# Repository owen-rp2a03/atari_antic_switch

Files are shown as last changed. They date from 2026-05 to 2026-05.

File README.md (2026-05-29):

# Atari NTSC/PAL Antic switch board

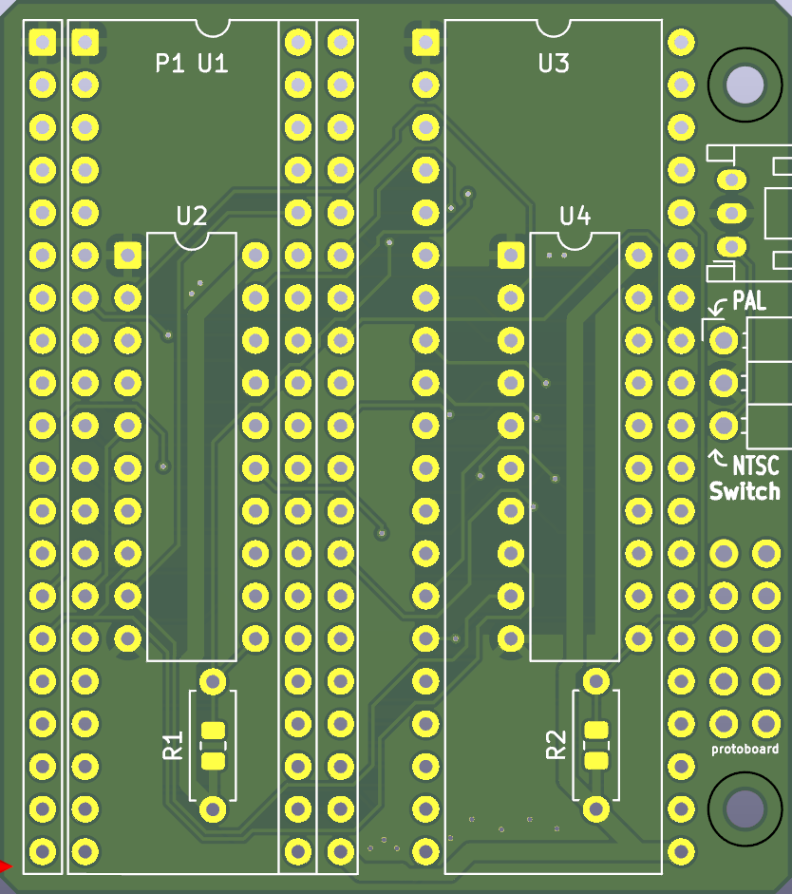
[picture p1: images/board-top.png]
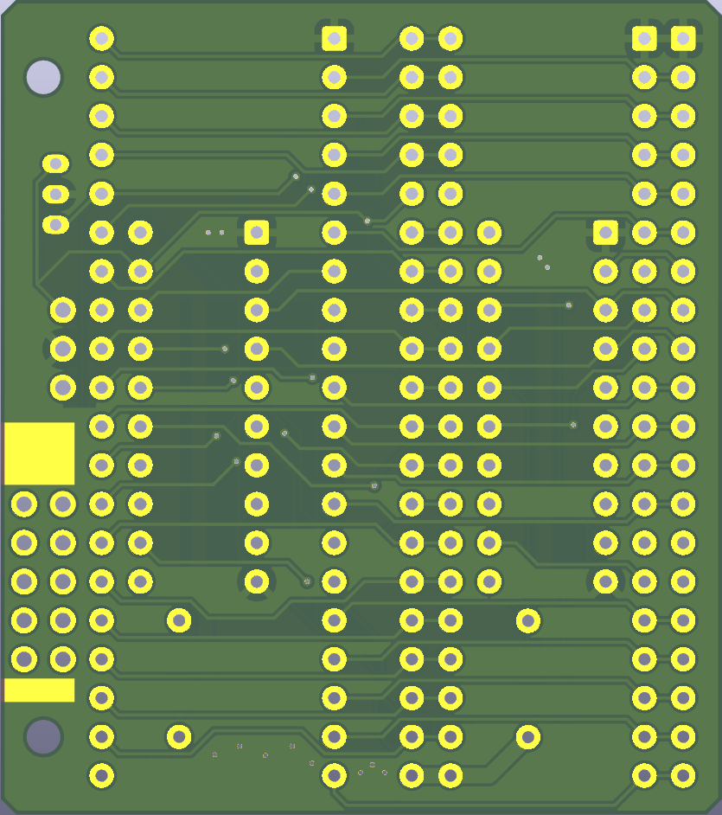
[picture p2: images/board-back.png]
	 (prototype)

Uses two '245 transceivers and holds reset on either Antic to disable them; isolating the control signals may not be necessary but doing it just in case.
Too many wires and two dip-40 chips for me to reliably test on cheap breadboards, so designed a theoretical circuit for a prototype pcb.

2026-5-17 - Untested prototype design

2026-5-28 - Boards recieved from PCBWay, confirmed not working, signal directions through bus tranciever need reworking due to my uncertainty of the i/o of the control lines for Antic.

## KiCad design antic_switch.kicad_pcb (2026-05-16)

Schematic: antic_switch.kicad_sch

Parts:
J1: 2.54; PinHeader_1x03_P2.54mm_Horizontal
J2: 2.00; JST_PH_S3B-PH-K_1x03_P2.00mm_Horizontal
P1: ANTIC_Conn
R1, R2: 10k; R_Axial_DIN0207_L6.3mm_D2.5mm_P7.62mm_Horizontal
SW2: SW_Push_SPDT
U1: ANTIC_NTSC
U2, U4: 74LS245; DIP-20_W7.62mm
U3: ANTIC_PAL

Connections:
/NTSC: J1.3, J2.1, R2.2, SW2.1 (A), U2.19 (CE), U3.36 (~RESET), U4.11 (B7)
/PAL: J1.1, J2.3, R1.2, SW2.3 (C), U1.36 (~RESET), U2.11 (B7), U4.19 (CE)
/R/~W: P1.14 (R/~W), U2.15 (B3), U4.15 (B3)
/~HALT: P1.9 (~HALT), U2.4 (A2), U4.4 (A2)
/~NMI: P1.7 (~NMI), U2.2 (A0), U4.2 (A0)
/~READY: P1.15 (~READY), U2.8 (A6), U4.8 (A6)
/~REF: P1.8 (~REF), U2.3 (A1), U4.3 (A1)
/~RESET: P1.36 (~RESET), U2.9 (A7), U4.9 (A7)
GND: J1.2, J2.2, P1.1 (VSS), SW2.2 (B), U1.1 (VSS), U2.1 (A->B), U2.10 (GND), U3.1 (VSS), U4.1 (A->B), U4.10 (GND)
unnamed: P1.13 (A0), U1.13 (A0), U3.13 (A0)
unnamed: P1.12 (A1), U1.12 (A1), U3.12 (A1)
unnamed: P1.11 (A2), U1.11 (A2), U3.11 (A2)
unnamed: P1.10 (A3), U1.10 (A3), U3.10 (A3)
unnamed: P1.28 (A4), U1.28 (A4), U3.28 (A4)
unnamed: P1.27 (A5), U1.27 (A5), U3.27 (A5)
unnamed: P1.26 (A6), U1.26 (A6), U3.26 (A6)
unnamed: P1.25 (A7), U1.25 (A7), U3.25 (A7)
unnamed: P1.24 (A8), U1.24 (A8), U3.24 (A8)
unnamed: P1.23 (A9), U1.23 (A9), U3.23 (A9)
unnamed: P1.16 (A10), U1.16 (A10), U3.16 (A10)
unnamed: P1.22 (A11), U1.22 (A11), U3.22 (A11)
unnamed: P1.17 (A12), U1.17 (A12), U3.17 (A12)
unnamed: P1.18 (A13), U1.18 (A13), U3.18 (A13)
unnamed: P1.19 (A14), U1.19 (A14), U3.19 (A14)
unnamed: P1.20 (A15), U1.20 (A15), U3.20 (A15)
unnamed: P1.2 (AN0), U1.2 (AN0), U3.2 (AN0)
unnamed: P1.3 (AN1), U1.3 (AN1), U3.3 (AN1)
unnamed: P1.5 (AN2), U1.5 (AN2), U3.5 (AN2)
unnamed: P1.30 (D0), U1.30 (D0), U3.30 (D0)
unnamed: P1.31 (D1), U1.31 (D1), U3.31 (D1)
unnamed: P1.32 (D2), U1.32 (D2), U3.32 (D2)
unnamed: P1.33 (D3), U1.33 (D3), U3.33 (D3)
unnamed: P1.40 (D4), U1.40 (D4), U3.40 (D4)
unnamed: P1.39 (D5), U1.39 (D5), U3.39 (D5)
unnamed: P1.38 (D6), U1.38 (D6), U3.38 (D6)
unnamed: P1.37 (D7), U1.37 (D7), U3.37 (D7)
unnamed: P1.35 (FI0), U1.35 (FI0), U3.35 (FI0)
unnamed: P1.34 (o0), U1.34 (o0), U3.34 (o0)
unnamed: P1.29 (o2), U1.29 (o2), U3.29 (o2)
unnamed: P1.4 (~LP), U1.4 (~LP), U3.4 (~LP)
unnamed: P1.6 (~RNMI), U1.6 (~RNMI), U3.6 (~RNMI)
unnamed: U1.14 (R/~W), U2.5 (A3)
unnamed: U1.9 (~HALT), U2.16 (B2)
unnamed: U1.7 (~NMI), U2.18 (B0)
unnamed: U1.15 (~READY), U2.12 (B6)
unnamed: U1.8 (~REF), U2.17 (B1)
unnamed: U3.14 (R/~W), U4.5 (A3)
unnamed: U3.9 (~HALT), U4.16 (B2)
unnamed: U3.7 (~NMI), U4.18 (B0)
unnamed: U3.15 (~READY), U4.12 (B6)
unnamed: U3.8 (~REF), U4.17 (B1)
VCC: P1.21 (Vcc), R1.1, R2.1, U1.21 (Vcc), U2.20 (VCC), U3.21 (Vcc), U4.20 (VCC)

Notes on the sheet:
from a8
in to a8

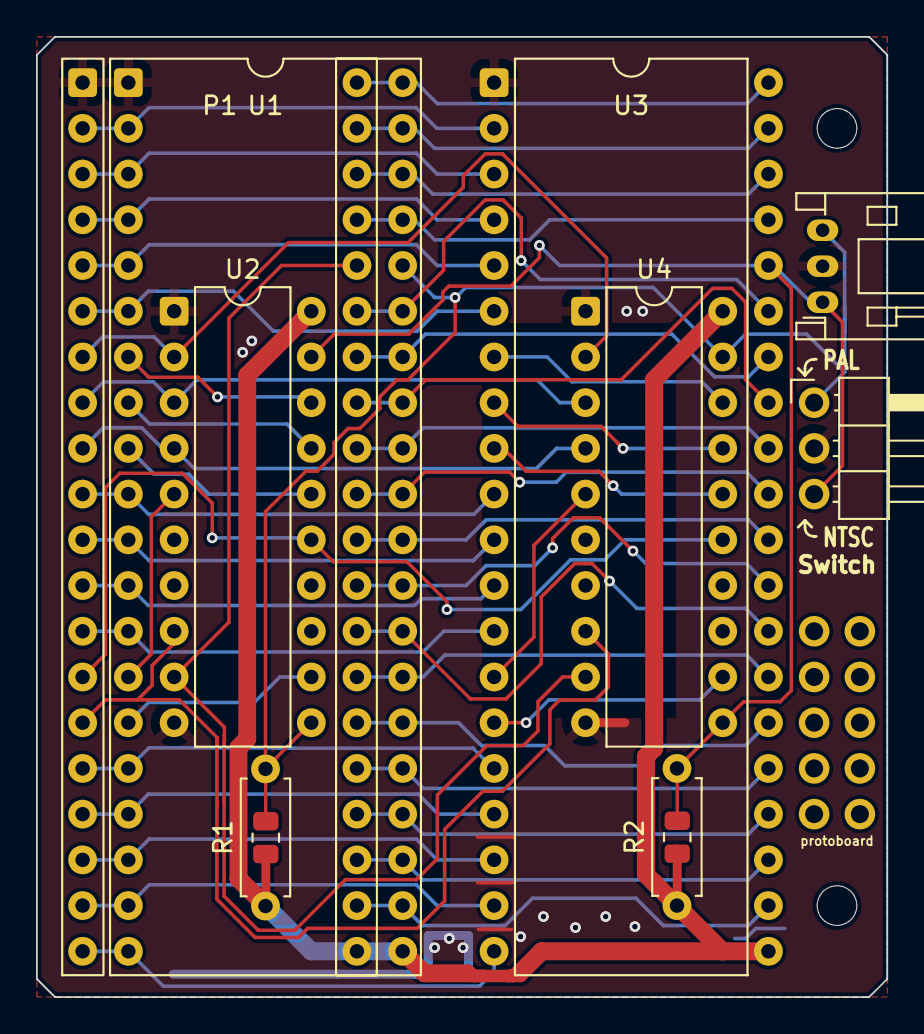
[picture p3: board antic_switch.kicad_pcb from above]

Board: 2 copper layers, 47.2 x 53.3 mm, 12 parts (0 on the bottom side), 52 nets.

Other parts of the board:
J3: 2.54; PinHeader_2x05_P2.54mm_Horizontal
MH1, MH2: MountingHole_2.2mm_M2
